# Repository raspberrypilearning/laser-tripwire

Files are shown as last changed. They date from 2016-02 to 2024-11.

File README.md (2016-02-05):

# A Raspberry Pi laser tripwire

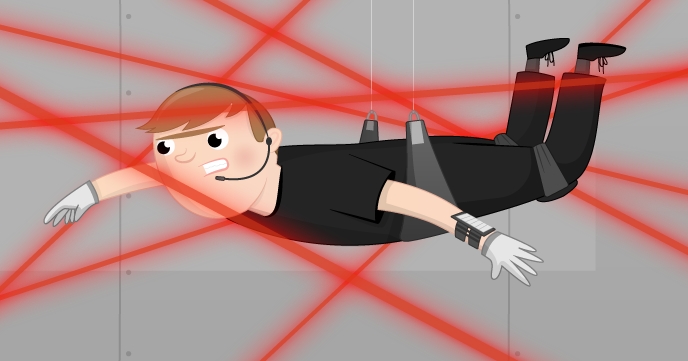
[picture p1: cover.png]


In this resource you will be making a laser tripwire. This can be used as a way to catch unwanted intruders coming into your bedroom, or as a game to see if you can avoid triggering the trap.

## Licence

Unless otherwise specified, everything in this repository is covered by the following licence:



***Laser Tripwire*** by the [Raspberry Pi Foundation](http://www.raspberrypi.org) is licenced under a [Creative Commons Attribution 4.0 International License](http://creativecommons.org/licenses/by-sa/4.0/).

Based on a work at https://github.com/raspberrypilearning/laser-tripwire

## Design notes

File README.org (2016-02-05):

* A Laser-tripwire with a Raspberry Pi
** [[file:full_guide.org][You can read the full guide here]]
** [[file:quick_guide.org][You can read the quick guide here]]
** [[https://youtu.be/4oJiXlPs46o][You can access the video guide here]]

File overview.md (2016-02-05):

In this resource you will make a laser tripwire, using a laser pointer and a Raspberry Pi.

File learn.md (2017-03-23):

By creating a laser tripwire with your Raspberry Pi, you will learn:

- How to use GPIO pins
- How to create a circuit on a breadboard
- Controlling GPIO pins with Python code and GPIO Zero
- How to use a capacitor to get readings from analogue sensors

This resource covers elements from the following strands of the [Raspberry Pi Digital Making Curriculum](https://www.raspberrypi.org/curriculum/):

- [Use basic programming constructs to create simple programs](https://www.raspberrypi.org/curriculum/programming/creator)
- [Combine inputs and/or outputs to create projects or solve a problem](https://www.raspberrypi.org/curriculum/physical-computing/builder)

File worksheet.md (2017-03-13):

# A Raspberry Pi laser tripwire

In this resource you will be making a laser tripwire. This can be used as a way to catch unwanted intruders coming into your bedroom, or as a prank to give somebody a little bit of a fright when they come into your house.

## Analogue inputs

In the world of electrical engineering, there are two type of input and output (I/O): analogue and digital. Digital I/O is fairly easy to understand; it's either *on* or *off*, *1* or *0*.

When talking about voltages and the Raspberry Pi, any input that is approximately below 1.8V is considered *off* and anything above 1.8V is considered *on*. For output, 0V is off and 3.3V is on.

Analogue I/O is a little trickier. With an analogue input, we can have a range of voltages from 0V up to 3.3V, and the Raspberry Pi is unable to detect exactly what that voltage is.

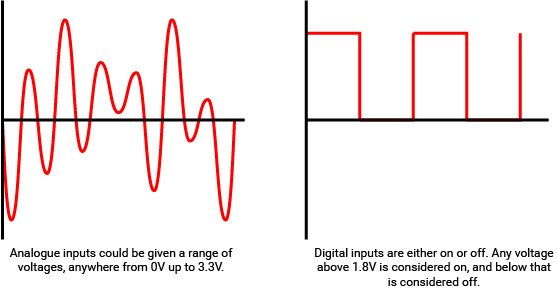
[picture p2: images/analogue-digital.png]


How, then, can we use a Raspberry Pi to determine the value of an analogue input, if it can only tell when the voltage to a GPIO pin goes above 1.8V?

### Using a capacitor for analogue inputs

Capacitors are electrical components that store charge.

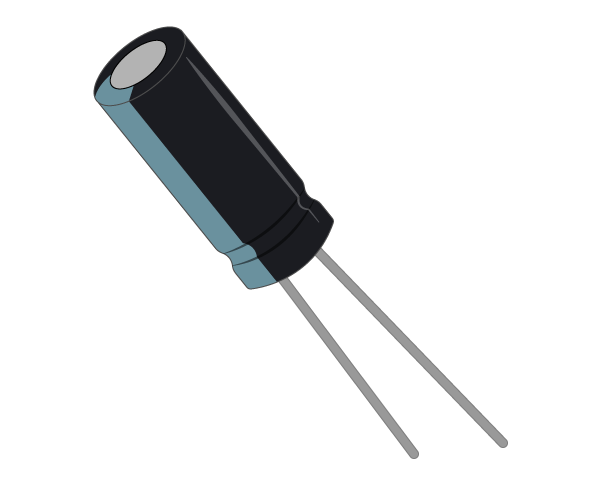
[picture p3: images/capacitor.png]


When current is fed into a capacitor it will begin to store charge. The voltage across the capacitor will start off low, and increase as the charge builds up.

By putting a resistor in series with the capacitor, you can slow the speed at which it charges. With a high resistance, the capacitor will charge slowly, whereas a low resistance will let it charge quickly.

If you time how long it takes the capacitor's voltage to get over 1.8V (or be *on*), you can work out the resistance of the component in series with it.

## Light-dependent resistors (LDRs)

An LDR (sometimes called a photocell) is a special type of resistor.

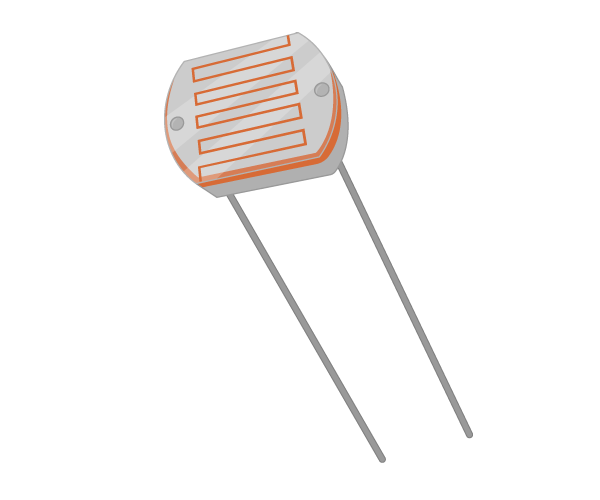
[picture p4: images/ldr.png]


When light hits the LDR, its resistance is very low, but when it's in the dark its resistance is very high.

By placing a capacitor in series with an LDR, the capacitor will charge at different speeds depending on whether it's light or dark.

## Creating a light sensing circuit

To begin, you're going to create a light sensing circuit with your Raspberry Pi.

1.  Place an LDR into your breadboard, as shown below:

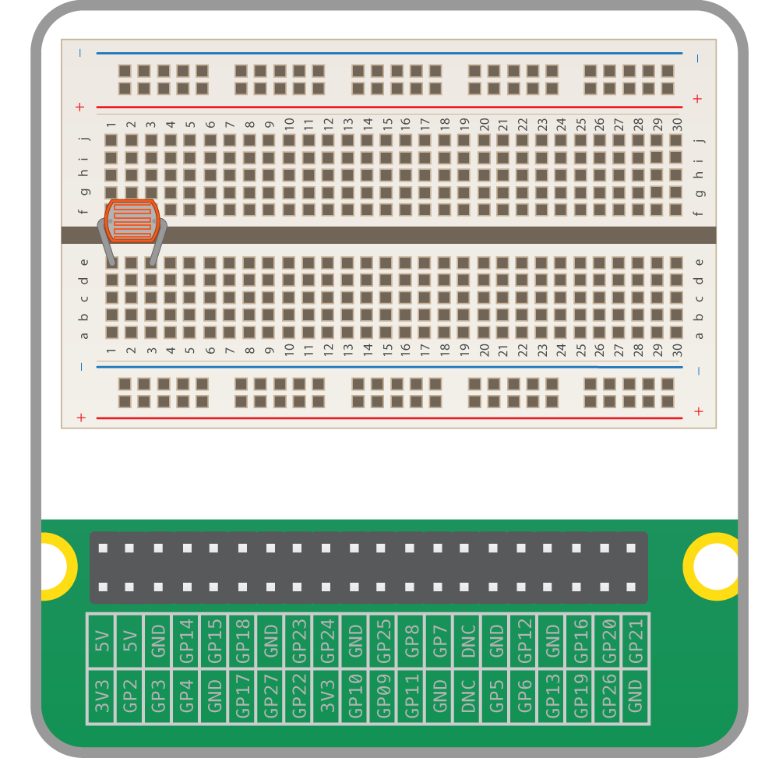
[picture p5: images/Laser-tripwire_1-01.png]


1.  Now place a capacitor in series with the LDR. As the capacitor is a polar component, you must make sure the long leg is on the same track as the LDR leg.

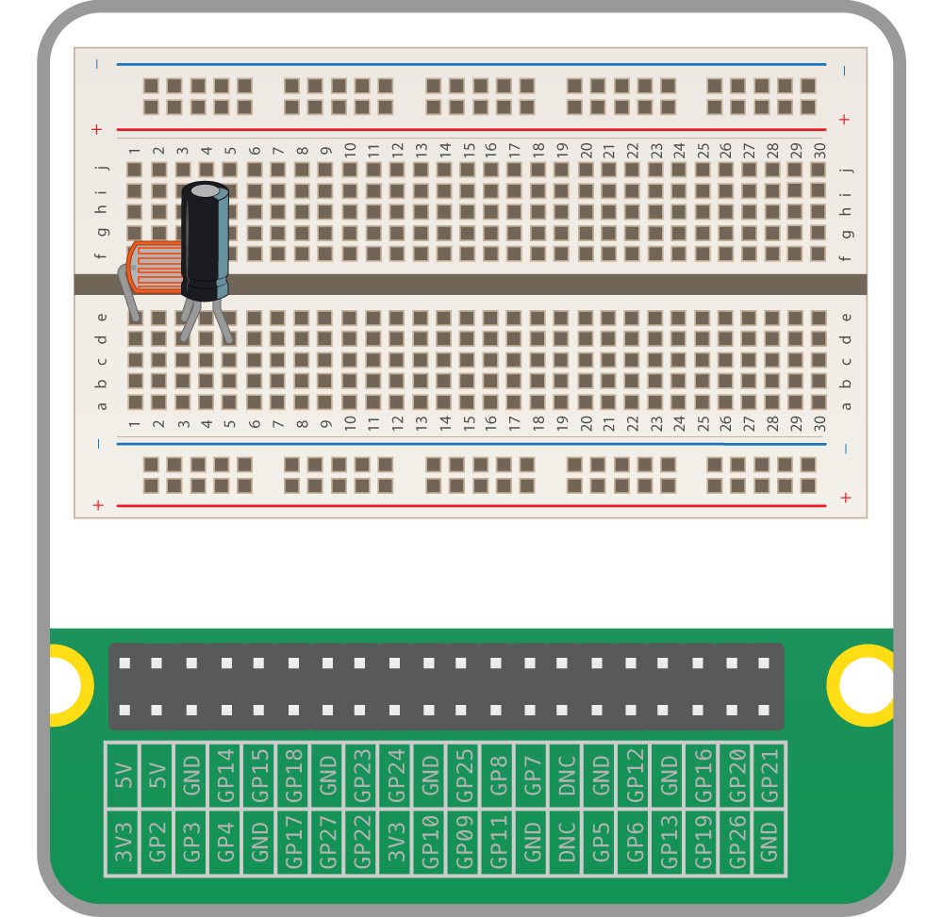
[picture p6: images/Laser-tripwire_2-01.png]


1.  Finally, add jumper leads to connect the two components to your Raspberry Pi.

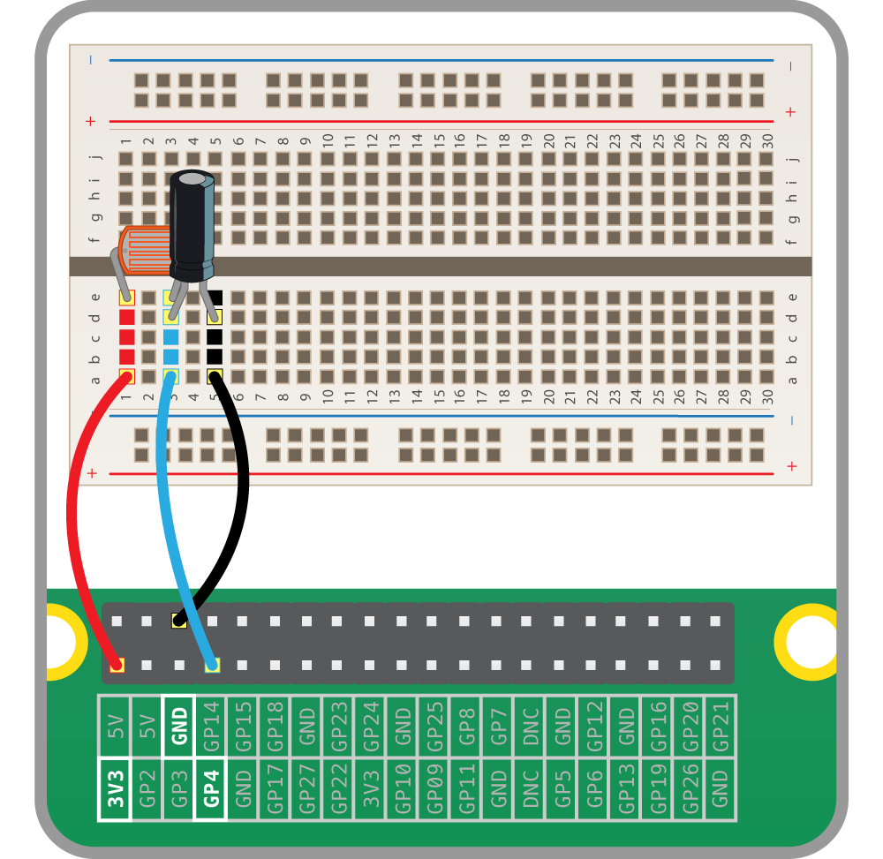
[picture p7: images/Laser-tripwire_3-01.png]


## Coding a light sensor

Luckily, most of the complicated code you would have to write to detect the light levels received by the LDR has been abstracted away by the `gpiozero` library. This library will handle the timing of the capacitor's charging and discharging for you.

Use the following code to set up the light sensor:

```python
  from gpiozero import LightSensor

  ldr = LightSensor(4)  # alter if using a different pin
```

Now run the code and switch over to the interpreter. Type `ldr.value` into the interpreter to see the light level currently recorded. Next, shine the laser pointer onto the LDR and type `ldr.value` into the interpreter again, to see the light level when the LDR is illuminated.

## Reducing light to the LDR

You probably noticed that unless you are in a dark room, there is little difference in the measured light levels when the LDR is illuminated by the laser, and when it's not. This can be fixed by reducing the amount of light that the LDR receives from other light sources in the room.

1.  Take an opaque drinking straw and cut a length from it between 2 and 5 cm long.
2.  Insert the head of the LDR into the straw.
3.  Type `ldr.value` into the interpreter again, then once more with the LDR illuminated by the laser.

You should now see a larger difference in the recorded light levels.

Wiring up the buzzer
--------------------

1.  The piezo buzzer is a polar component, like the capacitor. Place it into the breadboard, then connect the longer leg to GPIO 17 and the shorter leg into one of the ground pins.

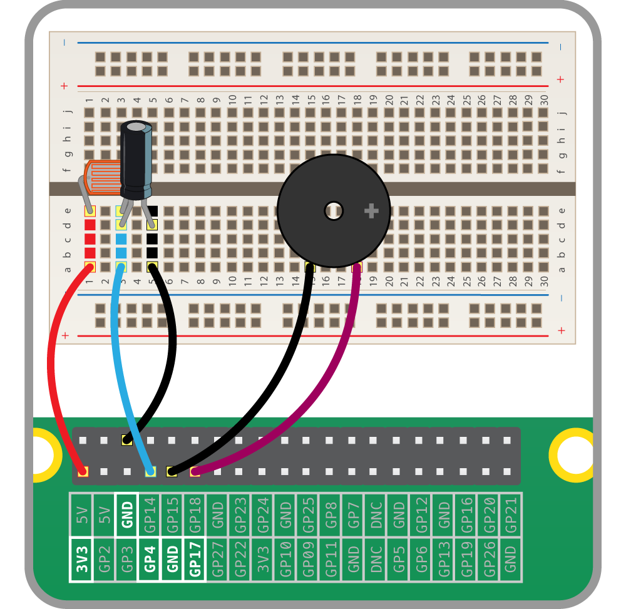
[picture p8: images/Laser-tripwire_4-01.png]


## Testing the buzzer

Next you can test that the buzzer is working.

1.  Alter the `import` line so it looks like this, so you can access the `Buzzer` class from `gpiozero`:

```python
from gpiozero import LightSensor, Buzzer
```

1.  Next, you need to tell the program which pin the buzzer is connected to:

```python
buzzer = Buzzer(17)
```

1.  Your script should now look like this:

```python
  from gpiozero import LightSensor, Buzzer

  ldr = LightSensor(4)  # alter if using a different pin
  buzzer = Buzzer(17)  # alter if using a different pin

```

1.  Run your code and then in the interpreter type the following:

```python
buzzer.on()
# and
buzzer.off()
```

This will switch the buzzer on and off. If it's not working, check your wiring and pin numbers.

## The tripwire code

You need a loop to constantly check the light level hitting the LDR. As long as the light level is high, you can assume the laser beam has not been broken. When the light level drops, the beam has been broken and the buzzer should sound.

To do this you can use an infinite loop. This is a loop that will keep going until you quit the program:

```python
  from gpiozero import LightSensor, Buzzer

  ldr = LightSensor(4)  # alter if using a different pin
  buzzer = Buzzer(17)  # alter if using a different pin

  while True:
```

Within the loop, you can use conditional selection to see if the light level falls below some threshold value. Start with `0.5`, but adjust it if you need to increase or decrease the sensitivity of the system:

```python
  from gpiozero import LightSensor, Buzzer

  ldr = LightSensor(4)  # alter if using a different pin
  buzzer = Buzzer(17)  # alter if using a different pin

  while True:
      if ldr.value < 0.5:  # adjust this to make the circuit more or less sensitive
          buzzer.on()
      else:
          buzzer.off()
```

If you were to run this now, it would fail. This is because the `while` loop runs so many times a second, it checks the light level faster than the capacitor charges and discharges. To slow the script down, you'll need to use the `time` library and add a `sleep` into the loop:

```python
  from gpiozero import LightSensor, Buzzer
  from time import sleep

  ldr = LightSensor(4)  # alter if using a different pin
  buzzer = Buzzer(17)  # alter if using a different pin

  while True:
      sleep(0.1)
      if ldr.value < 0.5:  # adjust this to make the circuit more or less sensitive
          buzzer.on()
          # uncomment the next line to have the alarm trigger for 30 seconds.
          # sleep(30) 
      else:
          buzzer.off()
```

Run the code and shine the laser onto the LDR. When you break the beam, the buzzer should sound.

## Packaging it all up

Once the circuit has been tested, you can wire up the components directly to the Raspberry Pi as shown below.

1.  Place a leg of the LDR and the long leg of the capacitor into a female-to-female jumper lead, then tape it up.

1.  Place jumper leads on the remaining legs, then plug it all back into the Raspberry Pi.

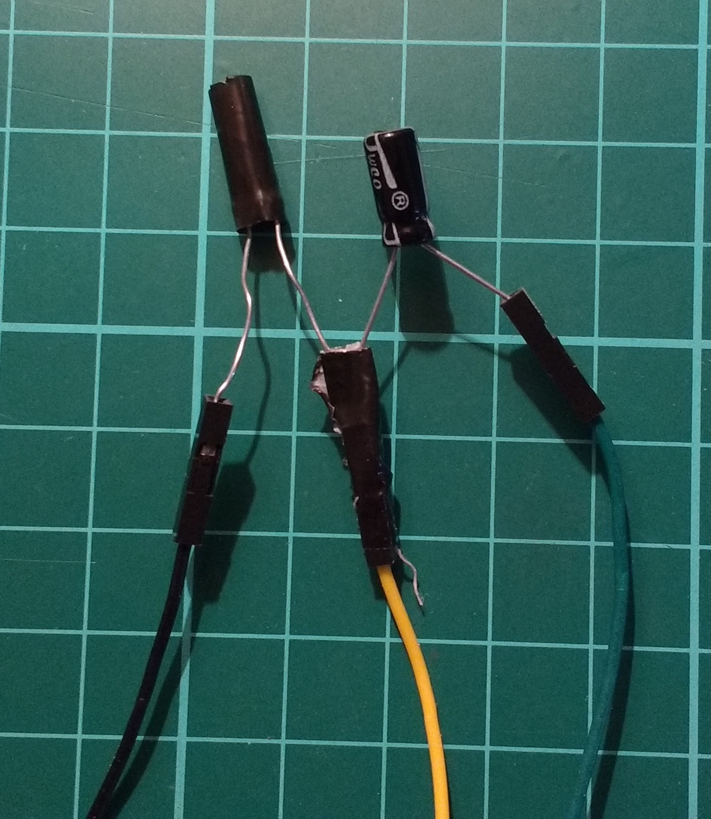
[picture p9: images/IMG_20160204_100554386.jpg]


You can place the Raspberry Pi and components in a housing to conceal them if you wish. Here we have used a plastic box with a hole made in it for the straw:

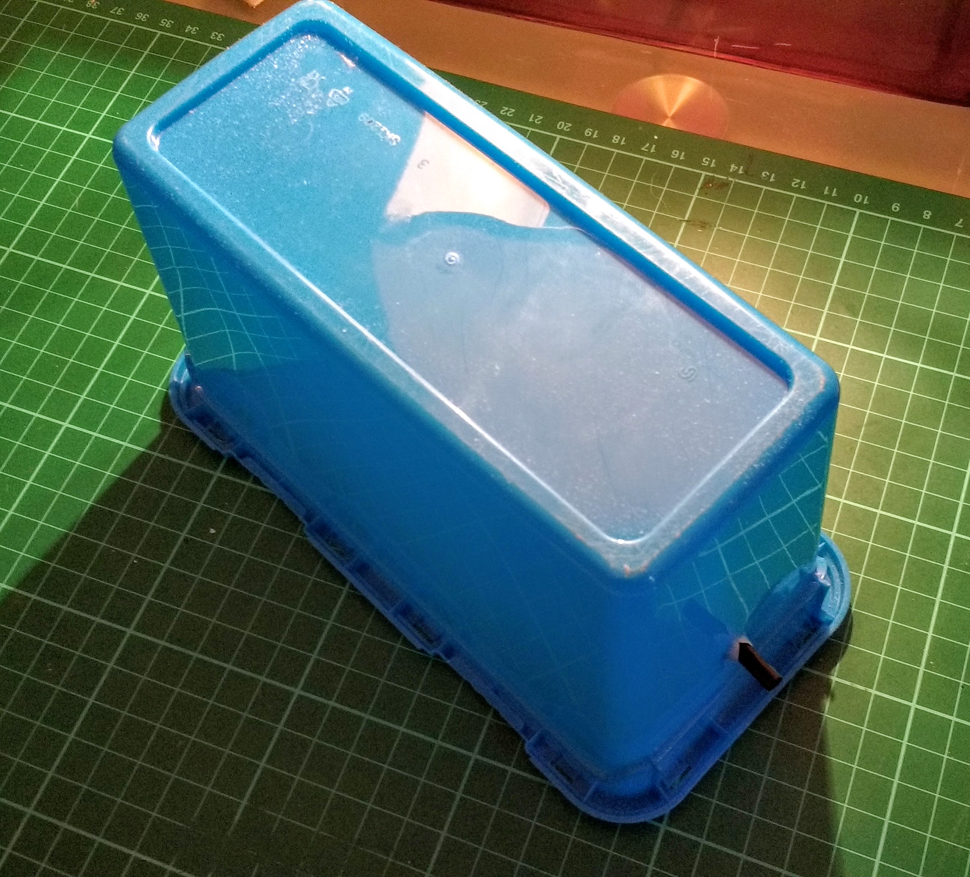
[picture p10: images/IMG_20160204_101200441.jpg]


1.  Place your container near a doorway and then affix the laser pointer to the wall, so the beam is focused down the straw.
1.  Now run the code and test your laser tripwire.

## Using a sound file and a speaker

1. If you have a speaker that you can plug into your Raspberry Pi, you can get your program to play a scary sound instead of sounding a buzzer.

1. First you'll need to choose an appropriate sound file. [This site](http://soundbible.com/royalty-free-sounds-1.html) has lots of sounds that you can use, and [this one](http://soundbible.com/71-Dog-Growling-And-Barking.html) is particularly appropriate. Once you have your sound you can use it in your program.

1. To play the sound with Python, you'll need to use the `pygame` library. Add this line below your `gpiozero` import.

    ``` python
    import pygame
    ```
1. Next you need to initialise Pygame and its sound mixer.

    ``` python
    pygame.init()
    pygame.mixer.init()
    ```
1. The sound file you used needs to be loaded up by your script. You can give it any name you like, just make sure you get the filename correct. You'll also need the length of the sound clip.

    ``` python
    growl = pygame.mixer.Sound('growl.mp3')
    length = growl.get_length()
    ```
1. Now, within the `while True:` loop, you can play the sound file instead of making the buzzer sound, and have it stop once the sound has finished playing.

    ``` python
    while True:
        sleep(0.1)
        if ldr.value < 0.5:  # adjust this to make the circuit more or less sensitive
            growl.play()
            sleep(length)
            growl.stop()

    ```
1. Have a play with different sounds to get the one that is most appropriate for your environment. Maybe you could use this on Halloween with a [witch's cackle](http://soundbible.com/33-Evil-Laugh-Cackle.html), to catch the kids trick or treating.

## What Next?
- Maybe you could try having a look at [Getting Started with the Twitter API](https://www.raspberrypi.org/learning/getting-started-with-the-twitter-api/), and have the tripwire tweet you when it is triggered.
- Why not add a Raspberry Pi Camera Module and use it to take a photo of the intruder? You can use [Getting Started with Picamera](https://www.raspberrypi.org/learning/getting-started-with-picamera/) to help you out.

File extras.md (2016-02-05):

You'll also need:

- A laser pointer (red works best)
- A drinking straw
- A box or plastic container

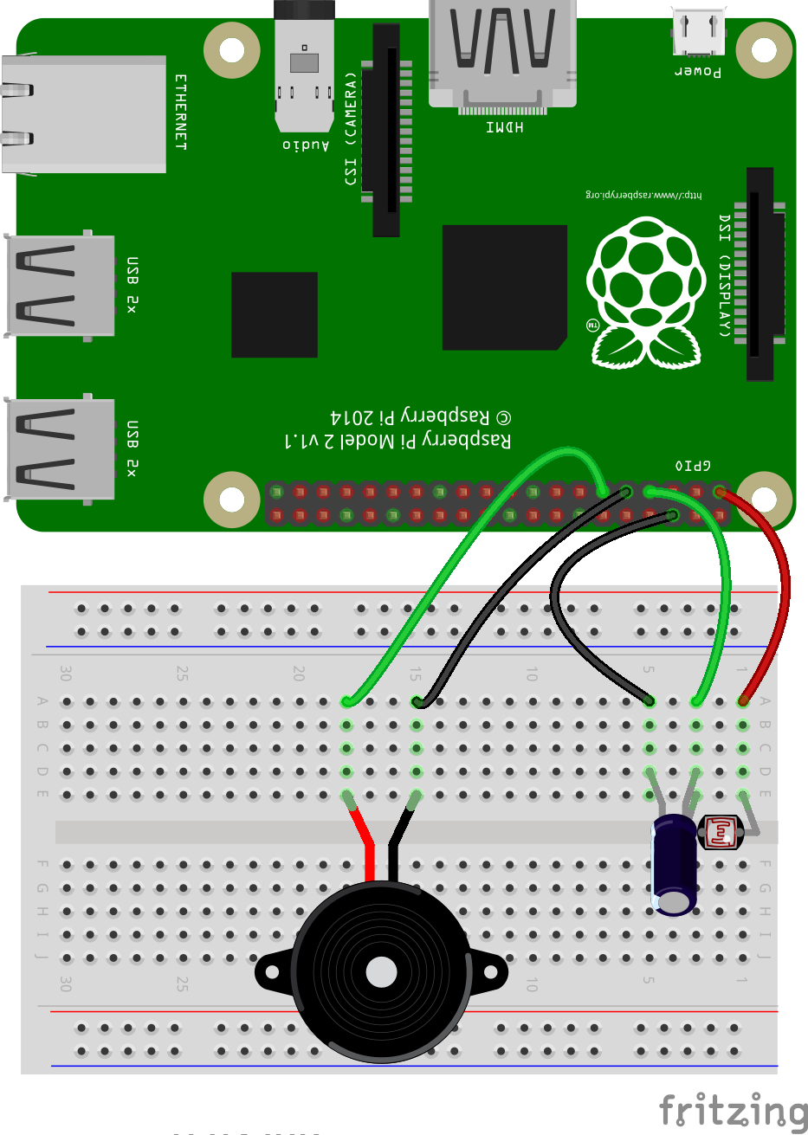
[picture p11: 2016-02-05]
en/images/LDR_with_buzzer.png

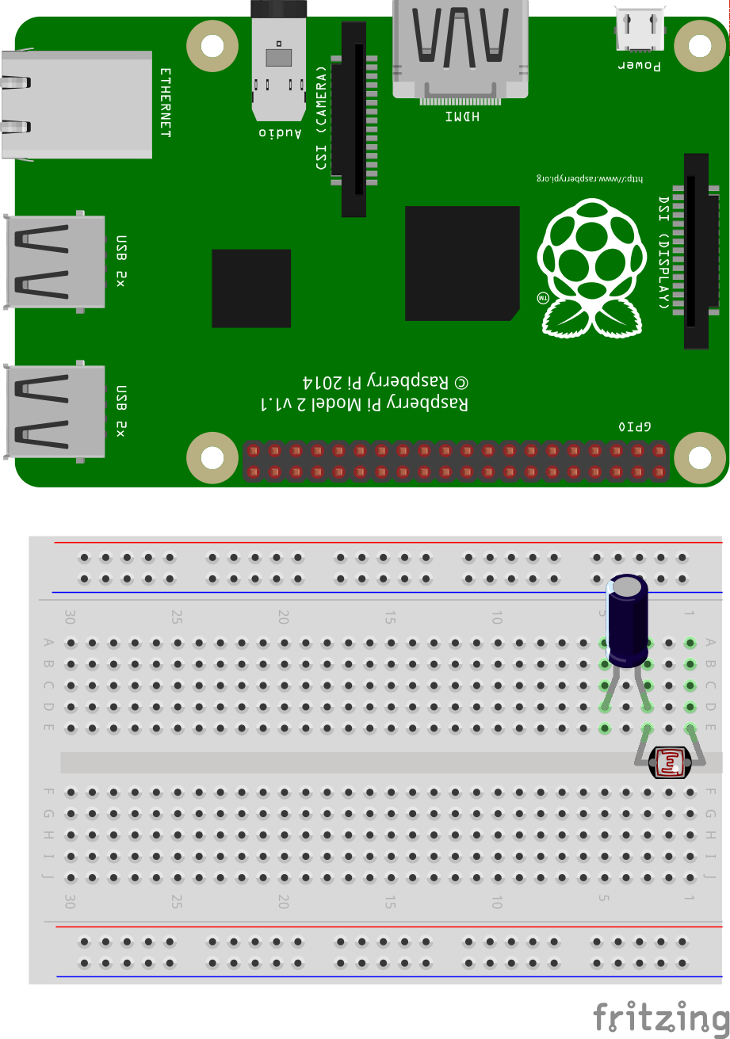
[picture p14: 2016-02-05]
en/images/LDR_and_cap.png

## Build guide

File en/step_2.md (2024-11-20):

## Detecting a broken beam

Create a simple prototype on a breadboard to detect whether or not a beam of light is hitting the **l**ight-**d**ependent **r**esistor (LDR).

--- task ---

Shield your LDR to make sure that only light from the laser pointer will trigger your program. You can do this with a small roll of paper, or even more easily with a section of a drinking straw.

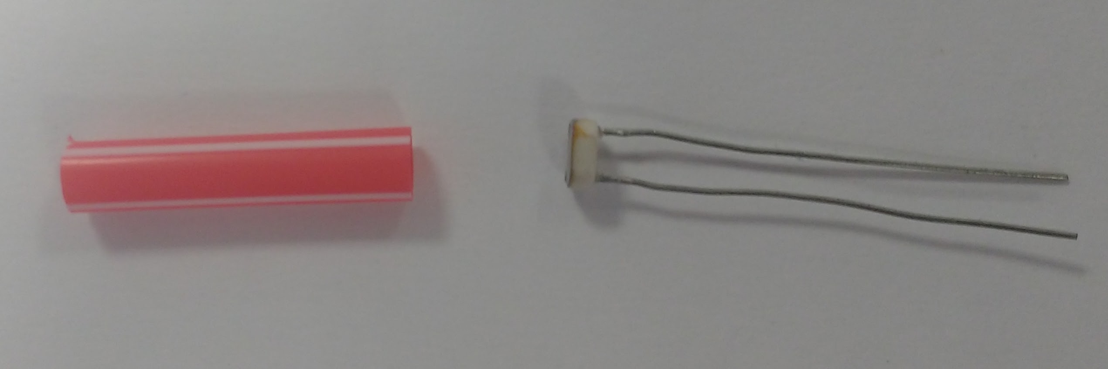
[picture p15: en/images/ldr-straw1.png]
ldr and straw

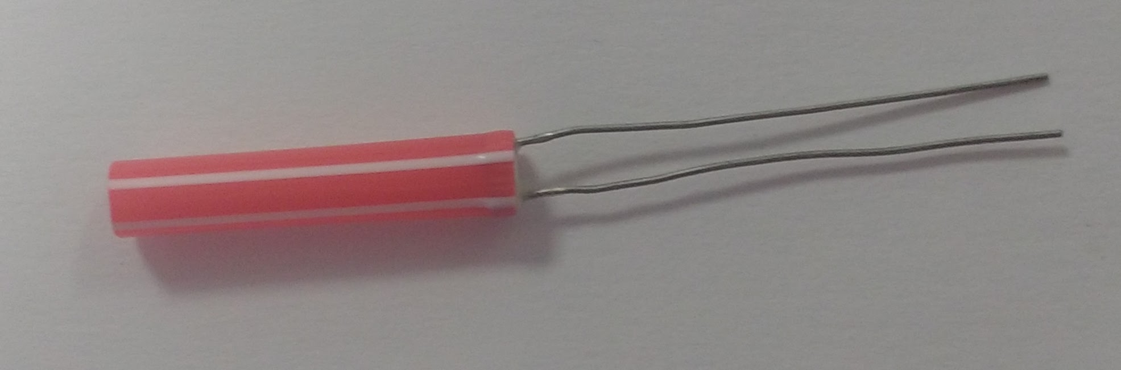
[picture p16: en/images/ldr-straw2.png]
ldr inserted into straw


--- /task ---

Set up a **r**esistor-**c**apacitor (RC) circuit using the 1µF capacitor and the LDR. 

--- task ---

Attach one leg of the LDR to a 3.3V pin (labeled **3V3**) of the Raspberry Pi. 

--- /task ---

--- task ---

Attach the other leg of the LDR to the positive leg of the capacitor.

--- /task ---

--- task ---

Connect the positive leg of the capacitor to a standard GPIO pin on the Raspberry Pi. 

--- /task ---

--- task ---

Attach the negative leg of the capacitor to a ground pin (labeled **GND**). 

--- /task ---

Here is one possible configuration of the circuit showing the positive leg of the capacitor attached to GPIO pin 4.

circuit

### The script on the Raspberry Pi

Write a script to detect when the laser beam is broken. You can use methods from the `gpiozero` module to do this.

--- task ---

Open Thonny.

--- /task ---

--- task ---

Import the `LightSensor` class from `gpiozero`.

```python
from gpiozero import LightSensor
```
 
--- /task ---

--- task ---

Create an 'ldr' object for the GPIO pin to which you have connected the LDR.

```python
from gpiozero import LightSensor
ldr = LightSensor(4))
```

--- /task ---

--- task ---

Use the `when_dark` method to trigger your `print`. 

```python
from gpiozero import LightSensor
ldr = LightSensor(4))
ldr.when_dark = lambda: print("INTRUDER")
```

--- /task ---

--- task ---

Save your script to `/home/username/tripwire.py`

**Note**: Change `username` to your username.

--- /task ---

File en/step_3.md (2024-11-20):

## Make some noise

There are two ways you can get you program to make some noise rather than just print 'INTRUDER'. 

### Buzzer

The first is to use a piezoelectric buzzer that is switched on when the laser beam is broken. 

--- task ---

Connect the positive leg of the buzzer to any **GPIO** pin on your Raspberry Pi, and the negative leg to a **Ground** pin. The positive leg is normally the longer of the two, and most buzzers are labelled to show which side is positive.

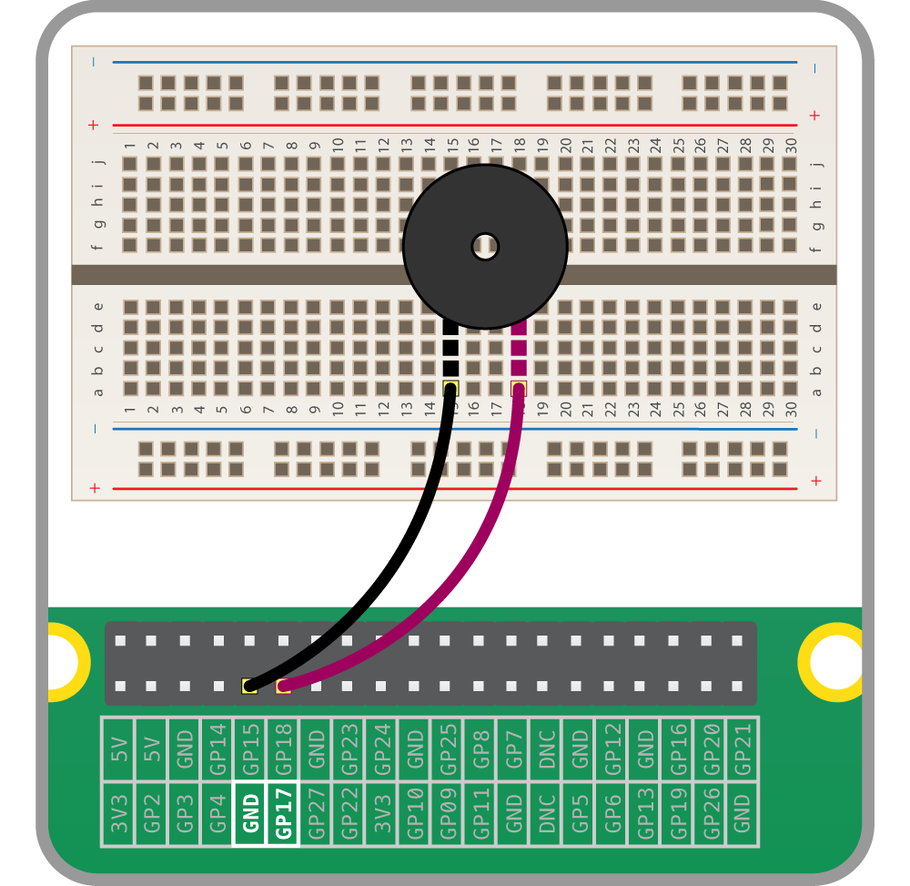
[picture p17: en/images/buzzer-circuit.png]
Buzzer circuit


--- /task ---

--- task ---

You can use the `Buzzer` class in `gpiozero` to turn it on and off again. The code below assumes that the buzzer has been wired to **GPIO 17**.

```python
from gpiozero import LightSensor, Buzzer
ldr = LightSensor(4))
buzzer = Buzzer(17)

ldr.when_dark = lambda: buzzer.beep(0.2, 0.2, 20)
```

--- /task ---

### Speakers

If you do not have a buzzer, you could use the PyGame module to play a sound through some speakers.

--- task ---

Download this sound file: <a href="resources/dog_bark.wav" download>dog_bark.wav</a>

--- /task ---

--- task ---

Move the sound file to your `/home/username/` folder.

**Note**: Change `username` to your username.

--- /task ---

--- task ---

Alter your `tripwire.py` Python script.

```python
from gpiozero import LightSensor
import pygame

ldr = LightSensor(4))

pygame.init()
my_sound = pygame.mixer.Sound('/home/username/dog_bark.wav')

ldr.when_dark = lambda: my_sound.play()
```

**Note**: Change `username` to your username.

--- /task ---

[This site](https://freesound.org/){:target="_blank"} has plenty of different sounds to choose from.

--- save ---

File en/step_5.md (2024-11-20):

## Run on boot

You can use `systemd` to run your code when Raspberry Pi starts up.

**Note** `systemd` is only available from Jessie versions of the Raspbian OS.

--- task ---

Open Terminal and type:

```bash
sudo nano /etc/systemd/system/tripwire.service
```

--- /task ---

--- task ---

Create your service.

```bash
[Unit]
Description=Laser Tripwire
After=multi-user.target

[Service]
Type=idle
ExecStart=/usr/bin/python3 /home/username/tripwire.py
Environment="PULSE_RUNTIME_PATH=/run/user/1000/pulse/"

[Install]
WantedBy=multi-user.target
```
**Note**: Change `username` to your username.
--- /task ---

--- task ---

Save and exit nano by pressing `Ctrl + x` and then press `y` when you are prompted to save.

--- /task ---

--- task ---

Tell systemd to enable your new service.

```bash
sudo systemctl daemon-reload
sudo systemctl enable tripwire.service
```

--- /task ---

--- task ---

Make sure your headphones or speakers are connected to your Raspberry Pi.

--- /task ---

--- task ---

**Test**: your service runs when you reboot your Raspberry Pi.

```bash
sudo reboot
```

--- /task ---

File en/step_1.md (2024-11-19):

## What you will make

Use a laser pointer, a few electronic components, and a Raspberry Pi to make a laser tripwire. Each time someone breaks the laser beam, the Raspberry Pi will use a buzzer or a speaker to sound the alarm.

--- no-print ---

<video width="640" height="360" controls>
<source src="images/laser_tripwire_video.mp4" type="video/mp4">
</video>

--- /no-print ---

### You will need:

- A Raspberry Pi
- A breadboard
- A 1µF capacitor
- A light-dependent resistor (LDR)
- 3 socket-pin jumper leads (for testing)
- 3 socket-socket jumper leads
- A laser pointer
- A drinking straw

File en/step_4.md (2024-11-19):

## Building your laser tripwire

Once the circuit has been tested, you can wire up the components directly to the Raspberry Pi.

--- task ---

Place one leg of the LDR and the long leg of the capacitor into a female-to-female jumper lead. Then tape it up to secure the legs.

--- /task ---

--- task ---

Place the remaining legs into jumper leads, then plug it all back into the Raspberry Pi.



--- /task ---

--- task ---

You can place the Raspberry Pi and components in a housing to conceal them if you wish. Here we have used a plastic box with a hole made in it for the straw:



--- /task ---

--- task ---

Place your container near a doorway. Then affix the laser pointer to the wall so the beam is focused down the straw.

--- /task ---

--- task ---

**Test**: Run the code and test your laser tripwire.

--- /task ---

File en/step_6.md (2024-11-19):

## Challenge

--- challenge ---

Include other events that are triggered when the tripwire is broken. 

--- task ---

Take a [picture](https://projects.raspberrypi.org/en/projects/rpi-picamera-take-photo) of the intruder.

--- /task ---

--- task ---

Use a laser component that can be run directly from the Raspberry Pi's GPIO pins. 

Here's an [example of a laser](https://www.rapidonline.com/laserfuchs-70103984-red-class-2-laser-10m-1mw-3-12vdc-25ma-650nm-wavelength-57-5868) you could buy.

--- /task ---

--- /challenge ---

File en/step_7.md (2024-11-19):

## What can you do now?

Try our [Physical computing](https://projects.raspberrypi.org/en/collections/physical_computing) project pathways where you will control and interact with the real world, combining code with electronics.

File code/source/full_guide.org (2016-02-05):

#+STARTUP:indent
#+HTML_HEAD: <link rel="stylesheet" type="text/css" href="css/styles.css"/>
#+HTML_HEAD_EXTRA: <link href='http://fonts.googleapis.com/css?family=Ubuntu+Mono|Ubuntu' rel='stylesheet' type='text/css'>
#+HTML_HEAD_EXTRA: <script> src="http://ajax.googleapis.com/ajax/libs/jquery/1.9.1/jquery.min.js" type="text/javascript"></script>
#+HTML_HEAD_EXTRA: <script src="js/navbar.js" type="text/javascript"></script>
#+OPTIONS: f:nil author:nil num:nil creator:nil timestamp:nil toc:nil html-style:nil
#+TITLE: The Laser-Tripwire: The full guide
#+AUTHOR: Marc Scott
* Laser-Tripwire
:PROPERTIES:
:HTML_CONTAINER_CLASS: container
:END:
** Instructions
:PROPERTIES:
:HTML_CONTAINER_CLASS: worksheet
:END:

In this resource you will be making a laser-tripwire. This can be used as a way to catch unwanted intruders coming into your bedroom, or as a game to see if you can avoid triggering the trap.

** Equipment
:PROPERTIES:
:HTML_CONTAINER_CLASS: worksheet
:END: 
You're going to need a few pieces of equipment to complete this project:

1. A Raspberry Pi (any model will do, but wiring may vary)
2. A Laser Pointer
3. A Breadboard
4. Female-Male and Female-Female Jumper leads
5. A Piezo Buzzer
6. An LDR
7. A 1μF Capacitor

** Analogue Inputs
:PROPERTIES:
:HTML_CONTAINER_CLASS: worksheet
:END:
- In the world of electrical engineering, their are two type of input and output (I/O) - Analogue and Digital.
- Digital I/O is fairly easy to understand. It is either /on/ or /off/, /1/ or /0/.
- When talking about the voltages and the Raspberry Pi, any input that is approximately below 1.8V is considered /off/ and anything above 1.8V is considered /on/. For output, then 0V is off and 3.3V is on.
- Analogue I/O is a little trickier. With an analogue input, we can have a range of voltages from 0V up to 3.3V, and the Raspberry Pi is unable to detect exactly what that voltage is.

- How then can we use a Raspberry Pi to determine the value of an analogue input, if it can only tell when the voltage to a GPIO pin goes above 1.8V?
** Using a Capacitor for analogue inputs
:PROPERTIES:
:HTML_CONTAINER_CLASS: worksheet
:END:
- Capacitors are electrical components that store charge.


- When current is fed into a capacitor it will begin to store charge. The voltage across the capacitor will start off low, and increase as the charge builds up.
- By putting a resistor in series with the capacitor, you can slow the speed at which it charges. With a high resistance, the capacitor will charge slowly. Whereas a low resistance will let it charge quickly.
- If you time how long it takes the capacitor's voltage to get over 1.8V (or be /on/), you can workout what the resistance of the component in series with it is.
** Light Dependent Resistors (LDRs)
:PROPERTIES:
:HTML_CONTAINER_CLASS: worksheet
:END:
- An LDR (sometimes called a photocell) is a special type of resistor.

- When light hits the LDR, its resistance is very low, but when it's in the dark its resistance is very high.
- By placing a capacitor in series with an LDR, the capacitor will charge at different speeds depending on whether it's light or dark.
** Creating a Light sensing circuit
:PROPERTIES:
:HTML_CONTAINER_CLASS: worksheet
:END:
To begin, you're going to create a light sensing circuit with your Raspberry Pi.
1. Place an LDR into your breadboard, as shown below.

2. Now place a capacitor in series with the LDR. As the capacitor is a polar component, you must make sure the long leg is on the same track as the LDR leg.

3. Finally add jumper leads to connect the two components to your Raspberry Pi.

** Coding a light sensor
:PROPERTIES:
:HTML_CONTAINER_CLASS: worksheet
:END: 
- Luckily most of the complicated code you would have to write, to detect the light levels received by the LDR has been abstracted away by the =gpiozero= library.
- This library will handle the timing of the charging and discharging of the capacitor for you.
- Use the following code to set up the light sensor.
#+begin_src python
  from gpiozero import LightSensor, Buzzer

  ldr = LightSensor(4)  # alter if using a different pin
#+end_src
- Now run the code and switch over to the interpreter.
- In the interpreter type =ldr.value= to see the light level currently recorded.
- Now shine the Laser pointer on to the LDR and type =ldr.value= into the interpreter again, to see the light level when the LDR is illuminated.
** Reducing light to the LDR
:PROPERTIES:
:HTML_CONTAINER_CLASS: worksheet
:END: 
- You probably noticed, that unless you are in dark room, there is little difference in the measured light levels when the LDR is illuminated by the laser, and when it is not.
- This can be fixed by reducing the amount of light that the LDR receives from other light sources in the room.
1. Take an opaque drinking straw and cut a length from it between 2 and 5 cm long.
2. Insert the head of the LDR into the straw.
3. Type =ldr.value= into the interpreter again, then once more with the LDR illuminated by the laser.
- Hopefully you can see a larger difference in the recorded light levels.
** Wiring up the buzzer
:PROPERTIES:
:HTML_CONTAINER_CLASS: worksheet
:END: 
1. The Piezo buzzer is a polar component, like the capacitor. Place it into the breadboard and connect the longer leg to GPIO 17 and the shorter leg into one of the ground pins.

** Testing the buzzer
:PROPERTIES:
:HTML_CONTAINER_CLASS: worksheet
:END: 
Next you can test the buzzer is working.
1. Alter the =import= line so it looks like this, so you can access the =Buzzer= class from =gpiozero=
#+begin_src python
from gpiozero import LightSensor, Buzzer
#+end_src
2. Next you need to tell the program which pin the buzzer is connected to.
#+begin_src python
buzzer = Buzzer(17)
#+end_src
3. You script should now look like this:
#+begin_src python
  from gpiozero import LightSensor, Buzzer

  ldr = LightSensor(4)  # alter if using a different pin
  buzzer = Buzzer(17)  # alter if using a different pin

#+end_src
4. Run your code and then in the interpreter you can type:
#+begin_src python
buzzer.on()
# and
buzzer.off()
#+end_src
to switch the buzzer on and off. If it is not working, check your wiring and pin numbers.
** The tripwire code
:PROPERTIES:
:HTML_CONTAINER_CLASS: worksheet
:END: 
- You need a loop, to constantly check the light level hitting the LDR. As long as the light level is high, you can assume the laser beam has not been broken. When the light level drops, the beam has been broken and the buzzer should sound.
- To do this you can use an infinite loop. This is a loop that will keep going until you quit the program.
#+begin_src python
  from gpiozero import LightSensor, Buzzer

  ldr = LightSensor(4)  # alter if using a different pin
  buzzer = Buzzer(17)  # alter if using a different pin

  while True:
#+end_src
- Within the loop, you can use conditional selection to see if the light level falls below some threshold value. Start with =0.5= but adjust it if you need to increase or decrease the sensitivity of the system.
#+begin_src python
  from gpiozero import LightSensor, Buzzer

  ldr = LightSensor(4)  # alter if using a different pin
  buzzer = Buzzer(17)  # alter if using a different pin

  while True:
      if ldr.value < 0.5:  # adjust this to make the circuit more or less sensitive
          buzzer.on()
      else:
          buzzer.off()
#+end_src
- If you were to run this now, it would fail. This is because the =while= loops runs so many times a second, it checks the light level faster than the capacitor charges and discharges. To slow the scrip down, you'll need the =time= library and add a =sleep= into the loop.
#+begin_src python
  from gpiozero import LightSensor, Buzzer
  from time import sleep

  ldr = LightSensor(4)  # alter if using a different pin
  buzzer = Buzzer(17)  # alter if using a different pin

  while True:
      sleep(0.1)
      if ldr.value < 0.5:  # adjust this to make the circuit more or less sensitive
          buzzer.on()
          # uncomment the next line to have the alarm trigger for 30 seconds.
          # sleep(30) 
      else:
          buzzer.off()
#+end_src
- Run the code and shine the laser onto the LDR.
- When you break the beam, the buzzer should sound.
** Packaging it all up
:PROPERTIES:
:HTML_CONTAINER_CLASS: worksheet
:END: 
- Once the circuit has been tested, you can wire up the components directly to the Raspberry Pi as shown below.
- Place a leg of the LDR and the long leg of the capacitor into a female-female jumper lead, then tape it up.
- Place jumper leads on the remaining legs, then plug it all back into the Raspberry Pi.

- You can place the Raspberry Pi and components in a housing to conceal them if you wish. Here we have used a plastic box with a hole pocked through it, for the straw.

- Place your container near a doorway and then affix the laser pointer to the wall, so the beam is focused down the straw.
- Now run the code and test your laser-tripwire.
** Badging this project
- You can gain a badge for this project by  evidencing the following and uploading it to the [[https://www.raspberrypi.org/education/badges][Raspberry Badge Site]]
  - Modify the project for the laser tripwire, so that it acts as race timer.
  - Add a button into your circuit
  - When the button is pushed, the timer should start
  - Each time the laser beam is broken, it should record the time.
  - When the button is pushed a second time the program is ended the times should be displayed.
** Video Guide
:PROPERTIES:
:HTML_CONTAINER_CLASS: instructions
:END: 
Below is the link to the video guide for this project
[[https://youtu.be/4oJiXlPs46o][Link to video]]

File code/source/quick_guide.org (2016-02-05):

#+STARTUP:indent
#+HTML_HEAD: <link rel="stylesheet" type="text/css" href="css/styles.css"/>
#+HTML_HEAD_EXTRA: <link href='http://fonts.googleapis.com/css?family=Ubuntu+Mono|Ubuntu' rel='stylesheet' type='text/css'>
#+HTML_HEAD_EXTRA: <script> src="http://ajax.googleapis.com/ajax/libs/jquery/1.9.1/jquery.min.js" type="text/javascript"></script>
#+HTML_HEAD_EXTRA: <script src="js/navbar.js" type="text/javascript"></script>
#+OPTIONS: f:nil author:nil num:1 creator:nil timestamp:nil toc:nil html-style:nil
#+TITLE: The Laser-Tripwire: A Quick Guide
#+AUTHOR: Marc Scott
* Guide
:PROPERTIES:
:HTML_CONTAINER_CLASS: quick
:END:
This is a quick guide to creating a Laser-tripwire with a Raspberry Pi.
** Equipment
:PROPERTIES:
:HTML_CONTAINER_CLASS: equipment
:END: 
1. A Raspberry Pi (any model will do, but wiring may vary)
2. A Laser Pointer
3. A Breadboard
4. Female-Male and Female-Female Jumper leads
5. A Piezo Buzzer
6. An LDR
7. A 1μF Capacitor
** The Circuit
:PROPERTIES:
:HTML_CONTAINER_CLASS: circuit
:END:

** Code
:PROPERTIES:
:HTML_CONTAINER_CLASS: scripts
:END: 
#+begin_src python
  from gpiozero import LightSensor, Buzzer
  from time import sleep

  ldr = LightSensor(4)  # alter if using a different pin
  buzzer = Buzzer(17)  # alter if using a different pin

  while True:
      sleep(0.1)
      if ldr.value < 0.5:  # adjust this to make the circuit more or less sensitive
          buzzer.on()
          # uncomment the next line to have the alarm trigger for 30 seconds.
          # sleep(30) 
      else:
          buzzer.off()
#+end_src

** Instruction
:PROPERTIES:
:HTML_CONTAINER_CLASS: instructions
:END: 
1. Wire up the Raspberry Pi and components as shown in the diagram above.
2. Write the code as shown above and run.
3. With the laser pointer aimed at the LDR, the buzzer should be off. If the beam is broken the buzzer should come on.
4. You can alter the triggering ldr value in the code.
5. It may help to surround the LDR with a cut-down drinking straw, to block out some ambient light.
6. Once the circuit has been tested, you can wire up the components directly to the Raspberry Pi as shown below. (Soldering will increase the longevity of the project).

7. You can place the Raspberry Pi and components in a housing to conceal them if you wish.

** Video Guide
:PROPERTIES:
:HTML_CONTAINER_CLASS: instructions
:END: 
[[https://youtu.be/4oJiXlPs46o][Link to video]]

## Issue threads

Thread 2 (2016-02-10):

Missing "what next?"

bennuttall, 2016-02-10:
The worksheet is missing a final "what next?" step. It's currently showing the final step header with the "what next" icon.

lauraclay, 2016-02-10:
Where are you seeing the 'what next?' icon? I can't see it on the live site.

The worksheet was always missing a 'what next?' step. If this is required of all resources, let me know so I can flag it when editing- that way incomplete resources won't go live.

bennuttall, 2016-03-18:
This is where I'm seeing it:

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

It's required of all worksheets in all resources, so that the step numbers are included.

Closed 2016-06-01.

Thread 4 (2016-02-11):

Capacitor orientation in breadboard diagrams

SteveAmor, 2016-02-11:
Ideally, the capacitor should be flipped horizontally so the grey stripe is on the ground side.   People sometimes look at pictures and forget to read the text.  Also, after time, someone may have "conveniently" cut both the capacitor legs the same length.

samalderhyde, 2016-02-11:
Thanks Steve, I'll make that change to the diagram now

bennuttall, 2016-06-01:
@samalderhyde did you do this?

samalderhyde, 2016-06-01:
I have now

Closed 2016-06-01.

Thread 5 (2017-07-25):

fritzing/images missing

raspberrypilearningbot, 2017-07-25:
/learning was expecting a file or directory at fritzing/images

Closed 2017-08-31.

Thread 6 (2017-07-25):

fritzing/images missing

raspberrypilearningbot, 2017-07-25:
/learning was expecting a file or directory at fritzing/images

Closed 2017-08-31.

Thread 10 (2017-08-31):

fritzing/images missing

raspberrypilearningbot, 2017-08-31:
/learning was expecting a file or directory at fritzing/images

Closed 2017-08-31.

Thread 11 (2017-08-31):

Missing child project

raspberrypilearningbot, 2017-08-31:
/learning expected a child project named generic-python-lambda-functions with content in en.

Closed 2017-09-19.

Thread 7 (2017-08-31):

fritzing/images missing

raspberrypilearningbot, 2017-08-31:
/learning was expecting a file or directory at fritzing/images

Closed 2017-08-31.

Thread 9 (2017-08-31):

fritzing/images missing

raspberrypilearningbot, 2017-08-31:
/learning was expecting a file or directory at fritzing/images

Closed 2017-08-31.

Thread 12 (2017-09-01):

fritzing/images missing

raspberrypilearningbot, 2017-09-01:
/learning was expecting a file or directory at fritzing/images

Closed 2017-09-19.

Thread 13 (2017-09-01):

fritzing/images missing

raspberrypilearningbot, 2017-09-01:
/learning was expecting a file or directory at fritzing/images

Closed 2017-09-19.

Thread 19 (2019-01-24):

en/solutions missing

raspberrypilearningbot, 2019-01-24:
/learning was expecting a file or directory at en/solutions

Closed 2019-01-24.

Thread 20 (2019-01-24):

en/solutions missing

raspberrypilearningbot, 2019-01-24:
/learning was expecting a file or directory at en/solutions

Closed 2019-01-24.

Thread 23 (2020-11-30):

Links for tweet and photo don't work, they return users to step 1 in the project

libxx1, 2020-11-30:
https://projects.raspberrypi.org/en/projects/laser-tripwire/5

I've emailed user to say we'll let hi know once fixed. Please assign back to me on resolution so I can email him before we close.

libxx1, 2021-01-05:
Hey @MarcScott  can you take a look at this please. It's the 'tweet' and 'picture' links. I'm not sure where the links are meant to point to as I can't find repositories for them or any mention in learning. Cheers, Liz

MarcScott, 2021-01-06:
Links updated

Closed 2021-01-06.

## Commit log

2016-02-05 capacitors image
2016-02-05 added markdown guide
    [hardware.yml]
2016-02-05 updated config files
    [hardware.yml]
2016-02-05 Copy edit
    [hardware.yml]
2016-02-10 cover and hardware update
    [hardware.yml]
2016-02-10 fixed hardware.yml
    [hardware.yml]
2016-03-15 Correct component reference
    [hardware.yml]
2016-04-06 update circuit diagram 4
2016-05-09 Add unit of electrical capacitance (F), close #3
    [hardware.yml]
2016-05-09 Expand LDR
    [hardware.yml]
2017-08-31 Add already copy edited from rpi-python-laser-tripwire
2017-08-31 Move folders into code
    [LDR.fzz, LDR_buzzer.fzz, LDR_true.fzz]
2017-09-01 Set copy edit and listed to true
    [LDR.fzz, LDR_buzzer.fzz, LDR_true.fzz]
2026-10-19 Remove extra bracket from LightSensor listings
    LightSensor(4)) was a syntax error in four listings across steps 2 and 3.
